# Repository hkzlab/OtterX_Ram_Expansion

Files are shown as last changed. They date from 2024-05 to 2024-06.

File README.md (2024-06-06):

# OtterX RAM Expansion

## Introduction

This card expands the RAM of your [OtterX](https://www.tindie.com/products/wavicle/otterx-8-bit-retro-computer/) (a DIY CommanderX16 compatible) computer to 2MB!

Once You switch [J27](https://github.com/RetroRemake/OtterX_Assembly/blob/main/OtterX%20Schematics.pdf) to enable the external RAM and install this board, the computer will automatically detect the 2MB.

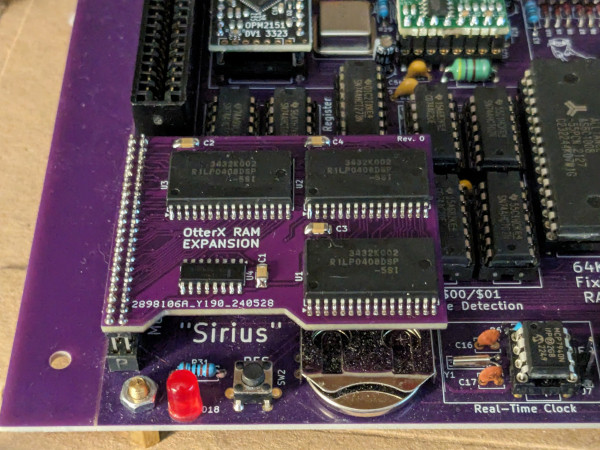
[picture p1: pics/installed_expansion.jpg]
Installed RAM Expansion


### Disclaimer

I take NO responsibility for what happens if you decide to build and use this card. Your computer might crash, catch fire or be destroyed in other nasty ways.
You're encourauged to take what you deem fit from this, and use it in your projects!

## Known Issues

### Rev. 0

- None

## Bill of Materials

| Component | Qty | Type / Value | Link |
| --- | --- | --- | --- |
| C1, C2, C3, C4 |  4  | 100nF / 1206 / ceramic | https://www.mouser.it/ProductDetail/581-1206YC104JAT2A |
| U4 |  1  | 74AC139 / SOIC-16 | https://www.mouser.it/ProductDetail/863-MC74AC139DR2G |
| U1, U2, U3 |  3  | 512Kx8 SRAM / SOP-32 | https://www.mouser.it/ProductDetail/968-R1LP0408DSP5SIS1 |
| J1 |  1  | 2x20 header, 2mm pitch | https://www.mouser.it/ProductDetail/200-MTMM12004TD157 or https://www.mouser.it/ProductDetail/200-MTMM12009LD350 |

Depending on whether you added or not a socket for the IC in the area where the expansion is installed, select one type of header or the other: `MTMM-120-09-L-D-350` clears the height for the sockets and the ICs.

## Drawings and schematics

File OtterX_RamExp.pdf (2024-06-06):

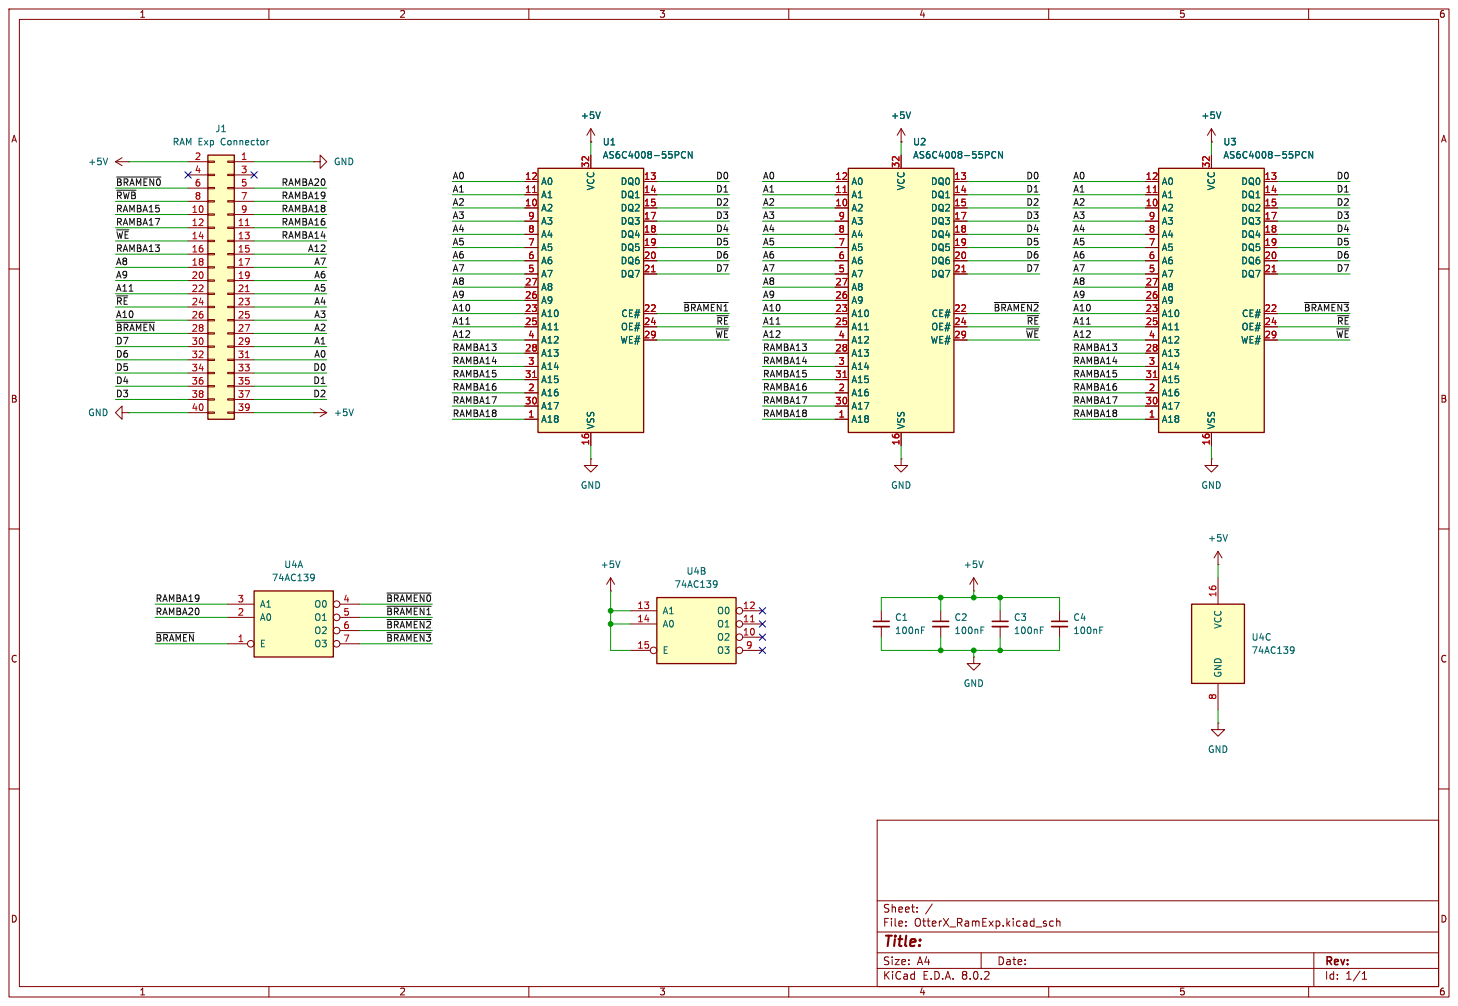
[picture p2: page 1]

Id: 1/1 Title: File: OtterX_RamExp.kicad_sch Sheet: /

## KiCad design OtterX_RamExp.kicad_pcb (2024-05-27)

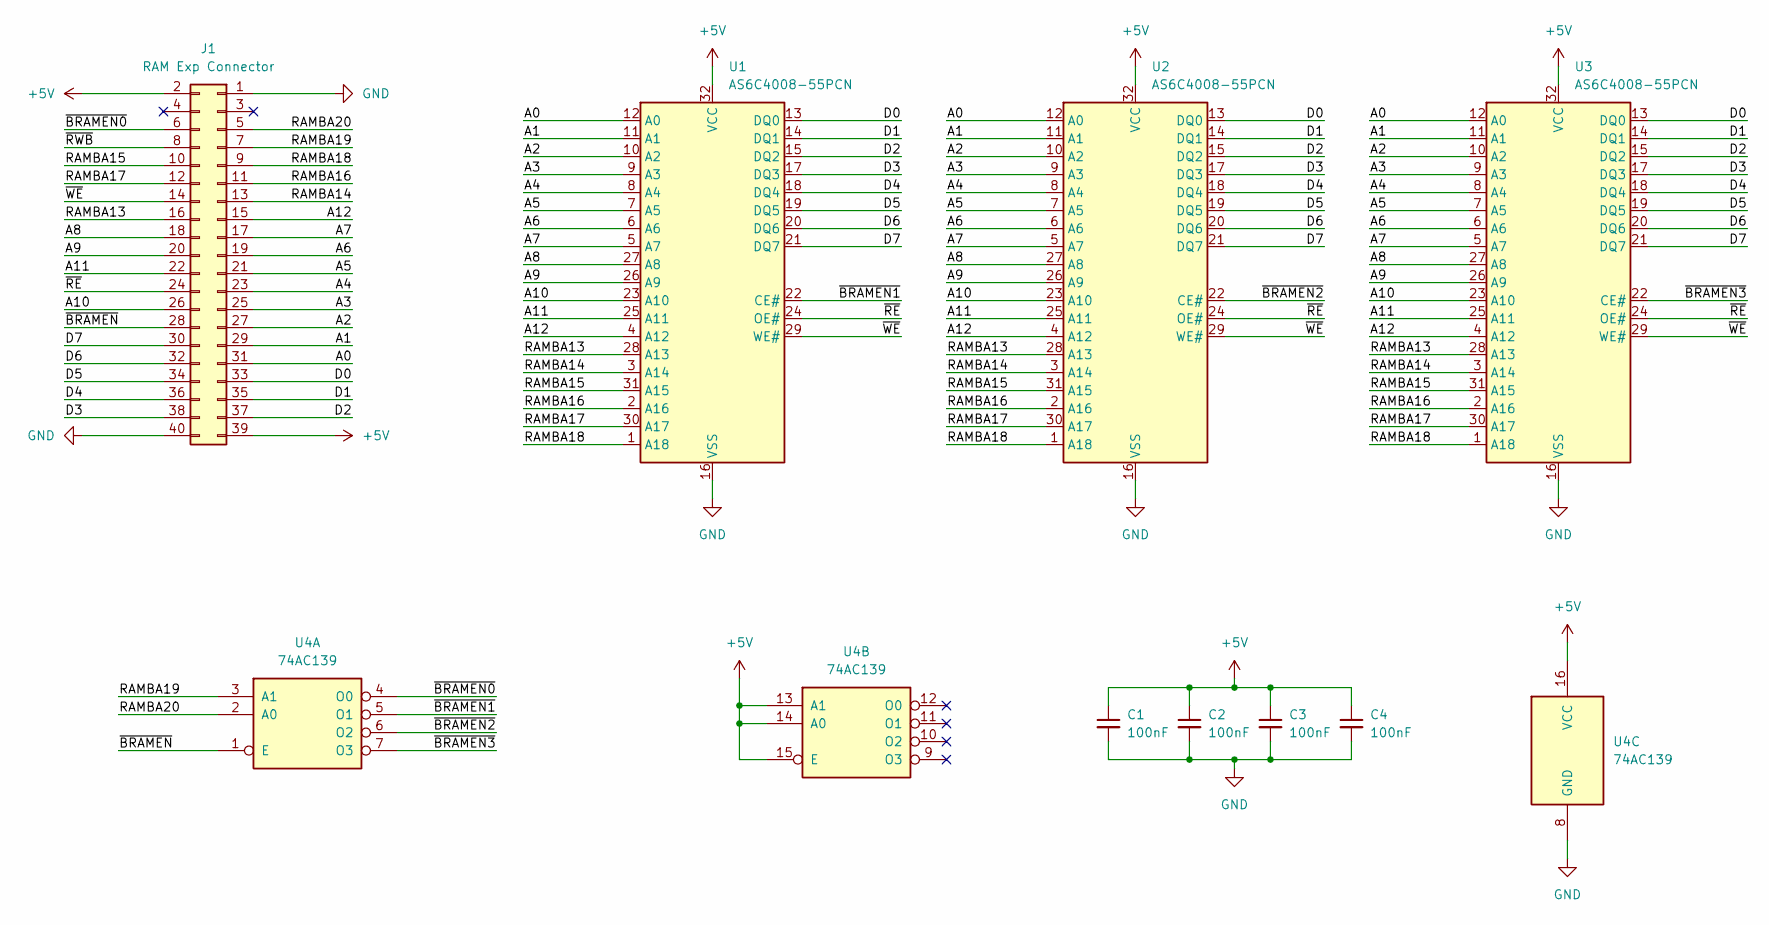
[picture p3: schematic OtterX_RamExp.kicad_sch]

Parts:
C1, C2, C3, C4: 100nF; C_1206_3216Metric_Pad1.33x1.80mm_HandSolder
J1: RAM Exp Connector; PinHeader_2x20_P2.00mm_Vertical
U1, U2, U3: AS6C4008-55PCN; SSOP-32_11.305x20.495mm_P1.27mm
U4: 74AC139; SO-16_3.9x9.9mm_P1.27mm

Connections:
+5V: C1.1, C2.1, C3.1, C4.1, J1.2, J1.39, U1.32 (VCC), U2.32 (VCC), U3.32 (VCC), U4.13 (A1), U4.14 (A0), U4.15 (E), U4.16 (VCC)
/A0: J1.31, U1.12 (A0), U2.12 (A0), U3.12 (A0)
/A1: J1.29, U1.11 (A1), U2.11 (A1), U3.11 (A1)
/A2: J1.27, U1.10 (A2), U2.10 (A2), U3.10 (A2)
/A3: J1.25, U1.9 (A3), U2.9 (A3), U3.9 (A3)
/A4: J1.23, U1.8 (A4), U2.8 (A4), U3.8 (A4)
/A5: J1.21, U1.7 (A5), U2.7 (A5), U3.7 (A5)
/A6: J1.19, U1.6 (A6), U2.6 (A6), U3.6 (A6)
/A7: J1.17, U1.5 (A7), U2.5 (A7), U3.5 (A7)
/A8: J1.18, U1.27 (A8), U2.27 (A8), U3.27 (A8)
/A9: J1.20, U1.26 (A9), U2.26 (A9), U3.26 (A9)
/A10: J1.26, U1.23 (A10), U2.23 (A10), U3.23 (A10)
/A11: J1.22, U1.25 (A11), U2.25 (A11), U3.25 (A11)
/A12: J1.15, U1.4 (A12), U2.4 (A12), U3.4 (A12)
/D0: J1.33, U1.13 (DQ0), U2.13 (DQ0), U3.13 (DQ0)
/D1: J1.35, U1.14 (DQ1), U2.14 (DQ1), U3.14 (DQ1)
/D2: J1.37, U1.15 (DQ2), U2.15 (DQ2), U3.15 (DQ2)
/D3: J1.38, U1.17 (DQ3), U2.17 (DQ3), U3.17 (DQ3)
/D4: J1.36, U1.18 (DQ4), U2.18 (DQ4), U3.18 (DQ4)
/D5: J1.34, U1.19 (DQ5), U2.19 (DQ5), U3.19 (DQ5)
/D6: J1.32, U1.20 (DQ6), U2.20 (DQ6), U3.20 (DQ6)
/D7: J1.30, U1.21 (DQ7), U2.21 (DQ7), U3.21 (DQ7)
/RAMBA13: J1.16, U1.28 (A13), U2.28 (A13), U3.28 (A13)
/RAMBA14: J1.13, U1.3 (A14), U2.3 (A14), U3.3 (A14)
/RAMBA15: J1.10, U1.31 (A15), U2.31 (A15), U3.31 (A15)
/RAMBA16: J1.11, U1.2 (A16), U2.2 (A16), U3.2 (A16)
/RAMBA17: J1.12, U1.30 (A17), U2.30 (A17), U3.30 (A17)
/RAMBA18: J1.9, U1.1 (A18), U2.1 (A18), U3.1 (A18)
/RAMBA19: J1.7, U4.3 (A1)
/RAMBA20: J1.5, U4.2 (A0)
/~BRAMEN0: J1.6, U4.4 (O0)
/~BRAMEN1: U1.22 (CE#), U4.5 (O1)
/~BRAMEN2: U2.22 (CE#), U4.6 (O2)
/~BRAMEN3: U3.22 (CE#), U4.7 (O3)
/~BRAMEN: J1.28, U4.1 (E)
/~RE: J1.24, U1.24 (OE#), U2.24 (OE#), U3.24 (OE#)
/~RWB: J1.8
/~WE: J1.14, U1.29 (WE#), U2.29 (WE#), U3.29 (WE#)
GND: C1.2, C2.2, C3.2, C4.2, J1.1, J1.40, U1.16 (VSS), U2.16 (VSS), U3.16 (VSS), U4.8 (GND)

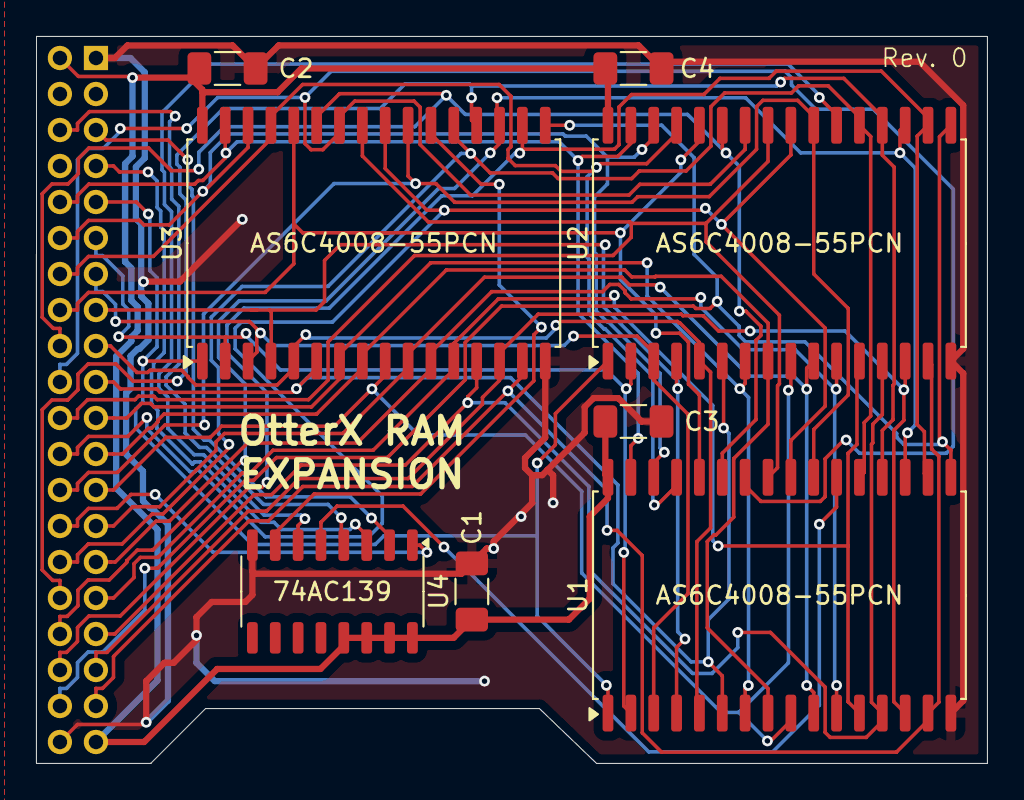
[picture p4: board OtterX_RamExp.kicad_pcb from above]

Board: 2 copper layers, 52.8 x 40.4 mm, 9 parts (1 on the bottom side), 38 nets.

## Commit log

2024-05-20 Add ram expansion PCB
    [OtterX_RamExp.kicad_pcb, OtterX_RamExp.kicad_sch]
2024-05-20 Update the PCB
    [OtterX_RamExp.kicad_pcb, OtterX_RamExp.kicad_sch]
2024-05-27 Add revision silkscreen
    [OtterX_RamExp.kicad_pcb]
2024-05-27 Added gerber
    [OtterX_RamExp.kicad_pcb]
2024-06-06 Filled in the README, added schematics
2024-06-06 You actually switch the jumper first...
